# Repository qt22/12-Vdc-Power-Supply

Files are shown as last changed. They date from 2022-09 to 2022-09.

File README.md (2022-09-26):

# 12-Vdc-Power-Supply

Design files created in Altium Designer

- Main IC: LT1083 **Low Dropout Voltage Regulator**
- Altium Project: DC-DC converter
- Schematic: LDO.SchDoc
- PCB: LDO.PcbDoc

### Main features:
- 18-27 Vdc input to 12 Vdc output stable power supply
- Max output current: 2A
- Input reverse polarity protection
- Board status indicator LED

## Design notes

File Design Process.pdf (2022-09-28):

# Design Documentation

## Jerry Tian

### Requirements

Input: 18-27 Vdc, reverse polarity protection Output: 11.9 Vdc -12.1 Vdc, 2A max, Indicator LED

### Result

18-27 Vdc to 12 Vdc 2A power supply

### Assumptions

DC input and DC output
Molex connector input and output Input <= 27 Vdc

### Research Notes

I started with brainstorming the options to step down the voltage, after talking to my professor, I narrowed it down to three options.

| Pros | Cons | Examples
Shunt Regulator | Very quiet Easy to understand | Max output current is very low Power inefficient | ZTL432BQ
Switch Mode Power Supply | Very power Efficient | Very hard to understand | LT3481
Low Dropout Regulator | Relatively quiet and power efficient | Create some heat | LT1085

After doing research on all three types, I decided to use a Switch Mode Power Supply ic. However, after reading the datasheet, I realized even though I could replicate the design in the datasheet, I don’t understand how the ic works at all. As a result, I moved to the other option, the Low Dropout Voltage Regulator. Below is my design process.

1. Understand Low Dropout Regulator: powered by a MOSFET and differential amplifier
2. Choose Low Dropout Regulator ic on Digikey, filter by input voltage range, max output voltage and output current.

3. Read the datasheet, verify max drop voltage is within acceptable range (6V), check output voltage formula sheet
Calculation of voltage divider:
Given: Vout = 12V, Vref is defined as the voltage difference between Vout and Adj pin, and from the datasheet, Vout = Vref(1+R2/R1), Imin = 10mA, Vref = 1.25V
Solve for: R1, R2
Solution:
12 = 1.25(1+R2/R1)
R2/R1 = 8.6 => R1/R2 = 0.116
max(R1 + R2) = Vout / Imin = 12V / 10mA = 1200 ohm
Select R1 as 100 ohm, the closest R2 we can select is 866 ohm Therefore R1 = 100 ohm, R2 = 866 ohm
4. LTSPICE simulation, verify calculation is correct

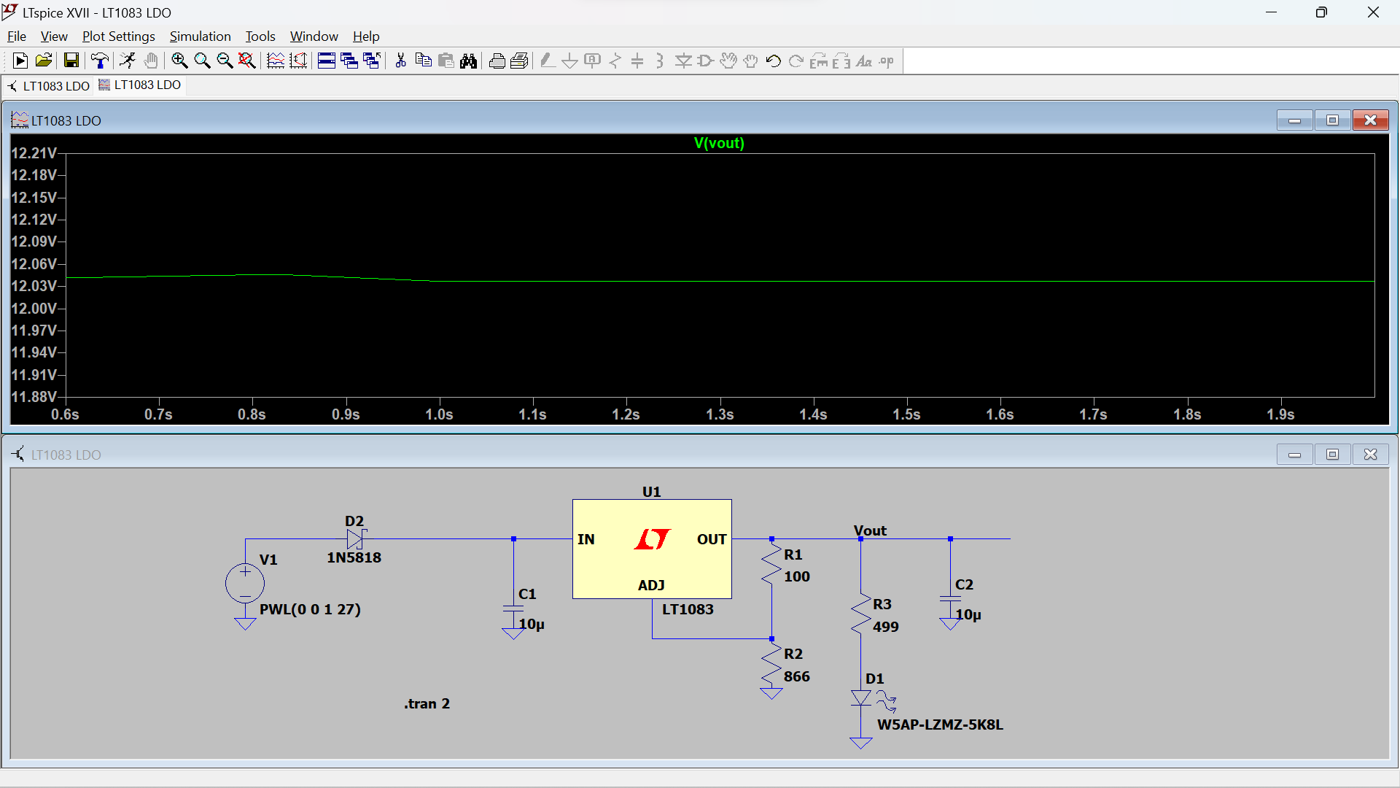
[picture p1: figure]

5. Schematic Design and component selection
a) Indicator LED calculation:
Given: Vout = 12 V, forward voltage = 2.2 V, forward current = 20 mA Solve for: Resistor
Solution:
Vr = 12-2.2 = 9.8V
R = Vr / Ir = 9.8V / 20mA = 490 ohm
The closest resistance is 499 ohm so I selected a 499 ohm resistor.
b) I selected a Schottky diode for input reverse polarity protection since the Schottky diode’s voltage drop is very low. There is another option that uses a regular diode if finance is a concern.

c) I believe there are better ways to regulate max output current but the design is very complicated. I chose the fuse since I understand it better.
6. Create PCB layout
a) I implemented the ground plane in my design after considering these benefits: Reduce air wiring on the pcb.
Since this is a power supply circuit, ground plane would reduce noise in both input and output connections
b) I divided the board into 2 regions, input region and output region. The power traces are set to 20 mils wide to handle 2A current. The power traces are lined up on a straight line since the board prioritizes 12 VDC output.
c) Since the low drop regulator IC steps down the voltage by dissipating heat, I added some holes under it to allow some air flow to lower the temperature.

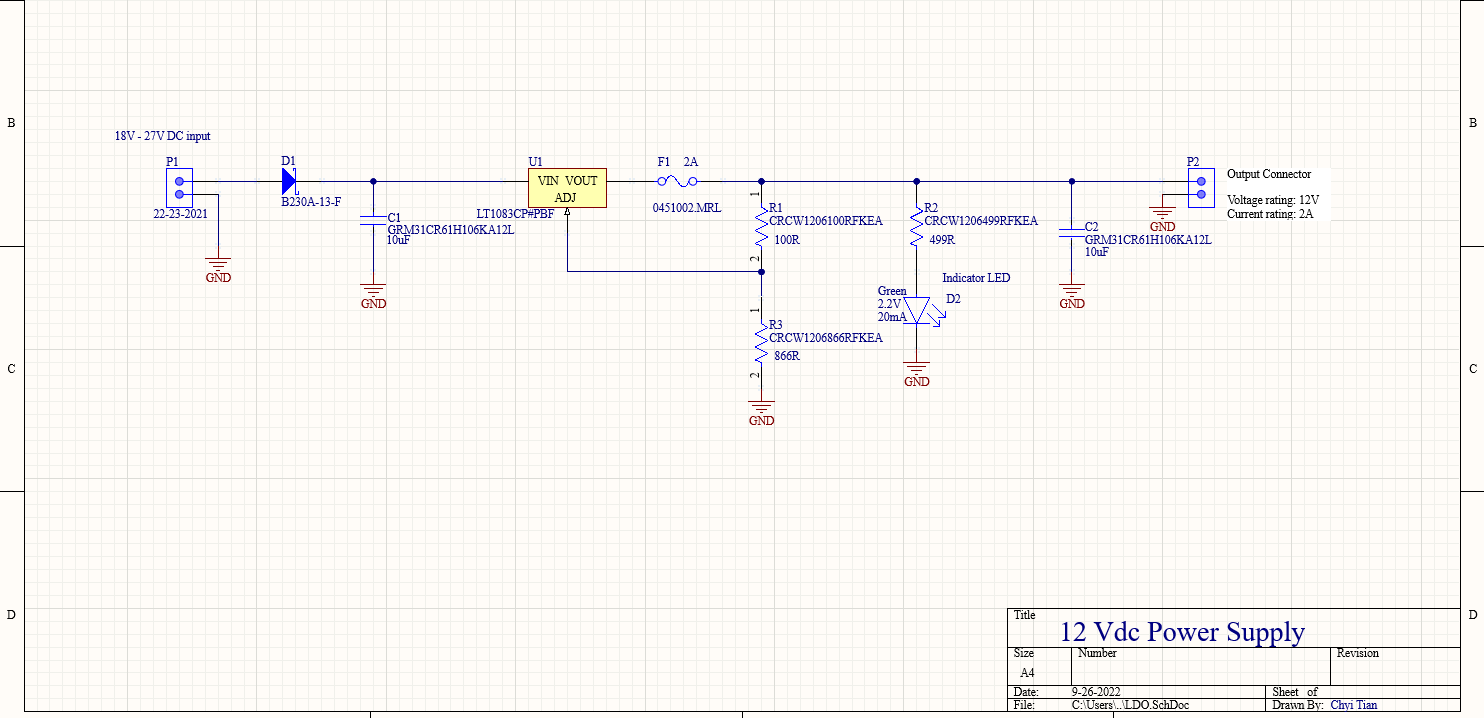
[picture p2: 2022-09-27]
schematic.png

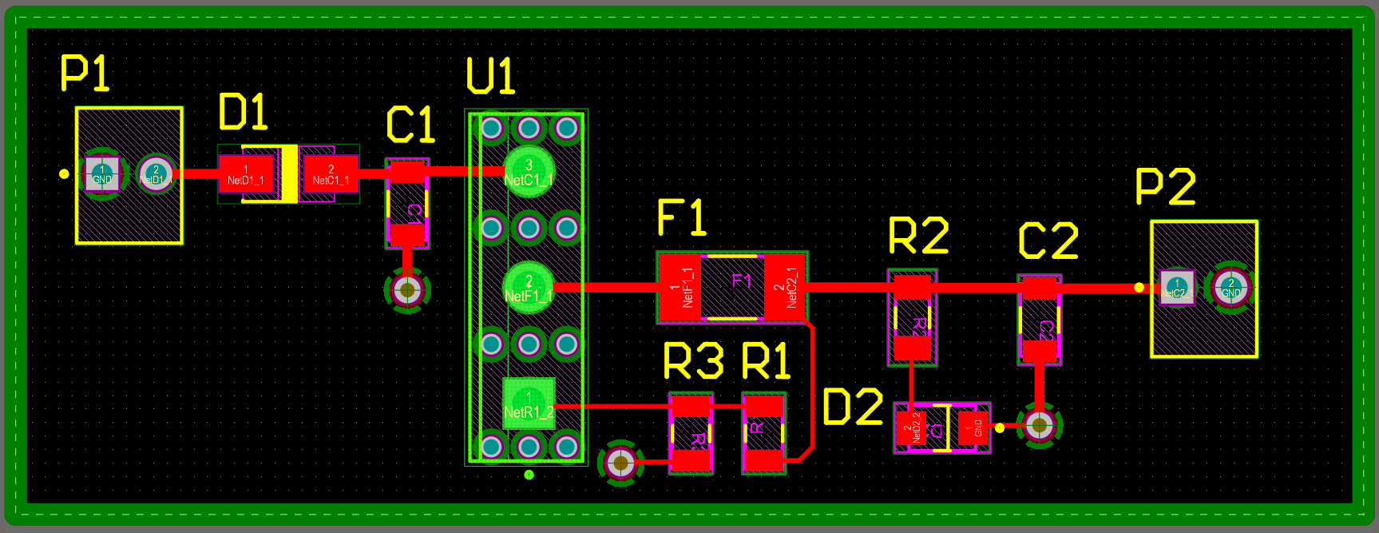
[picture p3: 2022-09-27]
PCB layout.png

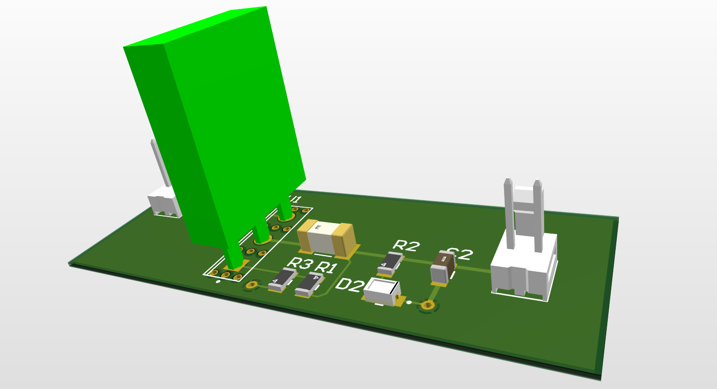
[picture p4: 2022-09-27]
PCB 3d view.png

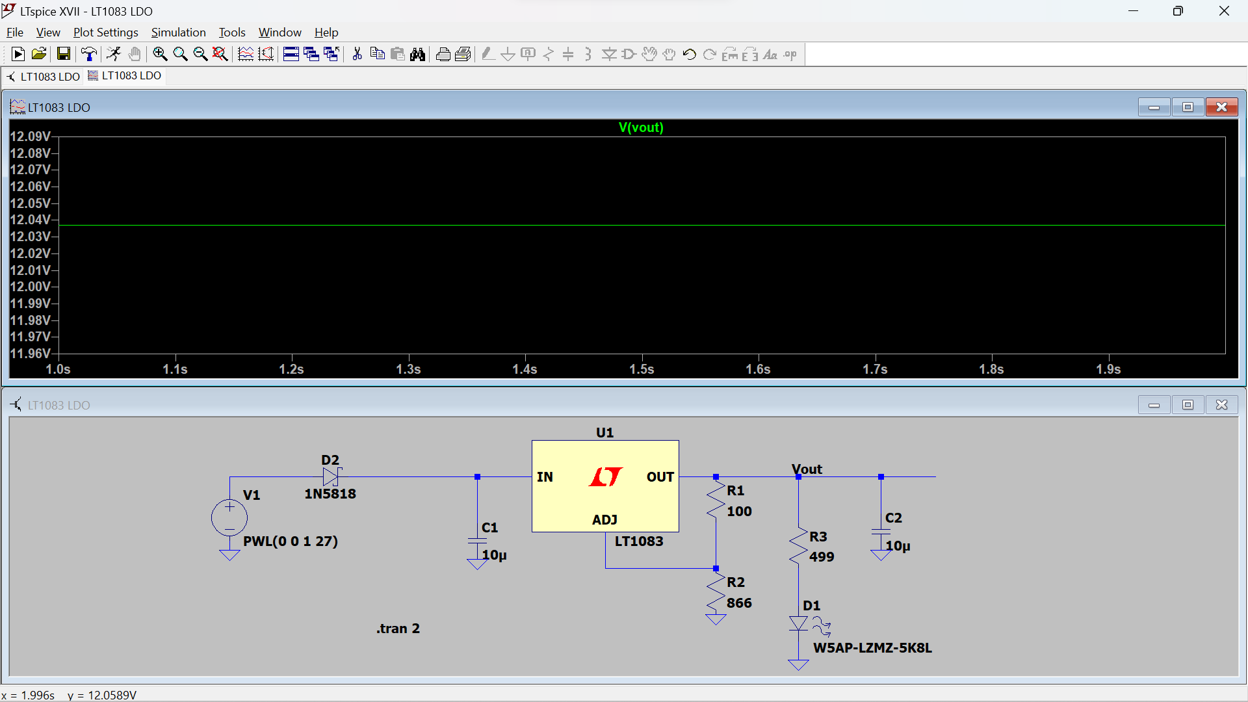
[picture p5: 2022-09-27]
Ltspice Simulation.png

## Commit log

2022-09-26 12 vdc power supply
    [DC_DC converter.PrjPcb, LDO.PcbDoc, LDO.SchDoc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]
2022-09-27 Upload design documents
    [DC_DC converter.PrjPcb, LDO.PcbDoc, LDO.SchDoc]
2022-10-06 Add feedback from the interview
    [LDO.PcbDoc, LDO.SchDoc]
